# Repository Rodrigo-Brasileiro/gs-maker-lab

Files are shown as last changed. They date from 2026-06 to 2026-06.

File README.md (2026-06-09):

# TPGN Maker GS - Braco Robotico de Coleta de Amostras

Projeto desenvolvido para a Global Solution 2026 da FIAP, com foco em Industria Espacial, usando Arduino, servomotores e modelagem 3D parametrica em OpenSCAD.

O sistema simula um braco robotico de 2 graus de liberdade para operacoes de docking & retrieval, isto e, captura, manipulacao e recolhimento de amostras ou pequenos detritos em um cenario inspirado em microgravidade.

## Visao geral

O prototipo e composto por:

| Area | Descricao |
| --- | --- |
| Controle | Firmware Arduino com comandos via Monitor Serial |
| Atuadores | 2 micro servos SG90: articulacao do braco e garra |
| Sinalizacao | LED de status para indicar garra fechada |
| Simulacao | Circuito publico no Tinkercad |
| Modelagem | Pecas mecanicas parametrizadas em OpenSCAD |
| Impressao 3D | Arquivos STL exportados para braco, base, elo e dedos da garra |

## Objetivo

Criar um demonstrador funcional de um mecanismo robotico simples, capaz de:

- Subir e descer a articulacao principal do braco.
- Abrir e fechar uma garra mecanica acionada por servo.
- Sinalizar visualmente quando a amostra esta capturada.
- Representar, em escala didatica, uma aplicacao de coleta de amostras, manutencao orbital ou captura de detritos espaciais.

## Integrantes

| Nome | RM |
| --- | --- |
| Guilherme Rocha Bianchini | RM97974 |
| Nikolas Rodrigues Moura dos Santos | RM551566 |
| Pedro Henrique Pedrosa Tavares | RM97877 |
| Rodrigo Brasileiro | RM98952 |
| Thiago Jardim de Oliveira | RM551624 |

Grupo: `TPGN - TechPulse Global Network`

## Links da entrega

| Recurso | Link |
| --- | --- |
| Simulador do circuito no Tinkercad | [Abrir projeto](https://www.tinkercad.com/things/aPYhfb0wO8s/editel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) |

## Estrutura do repositorio

```text
TPGN_MAKER_GS/
|-- README.md
|-- src/
|   `-- braco_robotico.ino
`-- model/
    |-- braco_robotico.scad
    |-- garra.scad
    |-- braco_robotico.stl
    |-- arm_base.stl
    |-- arm_link.stl
    |-- garra.stl
    |-- garra_base.stl
    |-- driver_finger.stl
    `-- follower_finger.stl
```

## Hardware e componentes

| Componente | Funcao |
| --- | --- |
| Arduino Uno R3 | Controlador do circuito |
| 2x micro servo SG90 9g | Movimento do braco e abertura/fechamento da garra |
| LED | Indicador de garra fechada |
| Resistor 220 ohm | Limitacao de corrente do LED |
| Fonte externa 5 V  | Alimentacao recomendada para os servos |
| Protoboard e jumpers | Conexoes eletricas |

Importante: para montagem fisica, os servos devem ser alimentados por fonte externa de 5 V ou 6 V, mantendo GND comum com o Arduino. Evite alimentar os servos diretamente pelo pino 5V do Arduino.

## Pinagem

| Pino Arduino | Conexao |
| --- | --- |
| `D9` | Sinal do Servo 1 - articulacao do braco |
| `D10` | Sinal do Servo 2 - garra |
| `D7` | LED de status com resistor de 220 ohm |
| `GND` | Terra comum entre Arduino, fonte e servos |

## Firmware

O firmware esta em [`src/braco_robotico.ino`](src/braco_robotico.ino) e usa a biblioteca padrao `Servo.h`.

Configuracoes principais:

| Parametro | Valor |
| --- | --- |
| Baud rate | `9600` |
| Angulo inicial do braco | `90` graus |
| Limite minimo do braco | `10` graus |
| Limite maximo do braco | `170` graus |
| Passo por comando | `15` graus |
| Garra aberta | `120` graus |
| Garra fechada | `30` graus |
| Delay de movimento | `15 ms` por grau |

## Comandos do Monitor Serial

Abra o Monitor Serial em `9600 baud`, envie um caractere e pressione Enter.

| Comando | Acao | Servo |
| --- | --- | --- |
| `U` | Sobe a articulacao do braco | Servo 1 |
| `D` | Desce a articulacao do braco | Servo 1 |
| `O` | Abre a garra | Servo 2 |
| `C` | Fecha a garra | Servo 2 |
| `H` | Volta as garras a posição inicial | Servo 1 e 2 |

Comportamento do LED:

- LED aceso: garra fechada, representando amostra capturada.
- LED apagado: garra aberta.
- Comandos invalidos são informados no Monitor Serial.

## Modelos 3D

Os modelos foram criados em OpenSCAD de forma parametrica, permitindo ajustar dimensoes, folgas, encaixes e layout de exportacao.

| Arquivo | Descricao |
| --- | --- |
| `model/garra.scad` | Modelo parametrico da garra com engrenagens gemeas |
| `model/braco_robotico.scad` | Montagem completa do braco 2-DOF, importando a garra |
| `model/garra.stl` | STL da garra montada |
| `model/garra_base.stl` | STL da base da garra |
| `model/driver_finger.stl` | STL do dedo motor da garra |
| `model/follower_finger.stl` | STL do dedo seguidor da garra |
| `model/braco_robotico.stl` | STL da montagem do braco |
| `model/arm_base.stl` | STL da base do braco |
| `model/arm_link.stl` | STL do elo do braco |

### Garra

A garra usa um mecanismo de engrenagens gemeas. Um servo aciona o dedo motor, enquanto o dedo seguidor acompanha o movimento por engrenamento, fechando de forma simetrica. As pontas possuem geometria concava para envolver uma amostra esferica de referencia.

### Braço

O arquivo `braco_robotico.scad` reutiliza os modulos de `garra.scad` e adiciona:

- Base do braço.
- Suporte do ombro.
- Elo principal.
- Acoplamento da garra ao punho.
- Suporte opcional para LED.

## Como reproduzir

1. Abra o projeto do Tinkercad pelo link da entrega.
2. Verifique se o circuito usa GND comum entre Arduino e fonte dos servos.
3. Inicie a simulacao.
4. Abra o Monitor Serial em `9600 baud`.
5. Envie os comandos `U`, `D`, `O`, `C` e `H` para testar os movimentos.
6. Para uso fisico, abra `src/braco_robotico.ino` na Arduino IDE e envie o codigo para um Arduino Uno.
7. Para visualizar ou alterar as pecas, abra os arquivos `.scad` no OpenSCAD.
8. Para exportar novos STLs, renderize com `F6` e use `File > Export > Export as STL`.

## Tecnologias utilizadas

- Arduino Uno
- Arduino IDE
- Biblioteca `Servo.h`
- Tinkercad Circuits
- OpenSCAD
- Modelos STL para impressao 3D

## Relacao com ODS

O projeto se conecta ao ODS 9 - Industria, Inovacao e Infraestrutura, pois explora automacao, prototipagem, sistemas embarcados e modelagem mecanica aplicados a um problema inspirado na industria espacial.

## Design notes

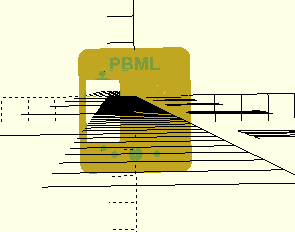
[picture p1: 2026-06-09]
imagens/suporte_vista_lateral.png

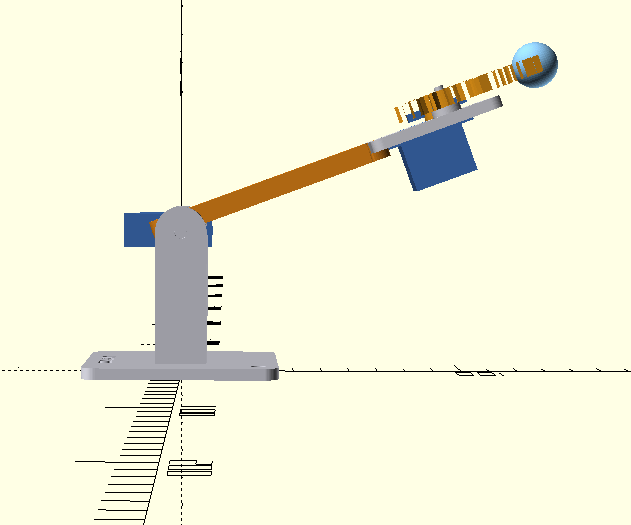
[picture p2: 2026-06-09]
imagens/vista_de_lado.png

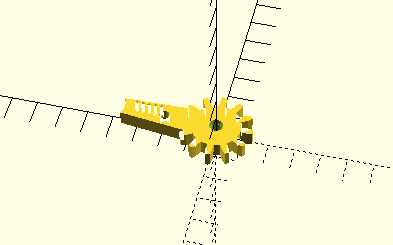
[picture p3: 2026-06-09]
imagens/garra_cilindrica.png

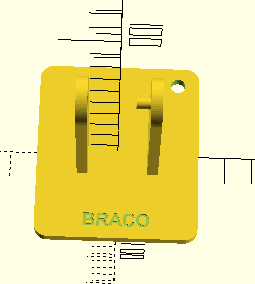
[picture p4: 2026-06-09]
imagens/suporte.png

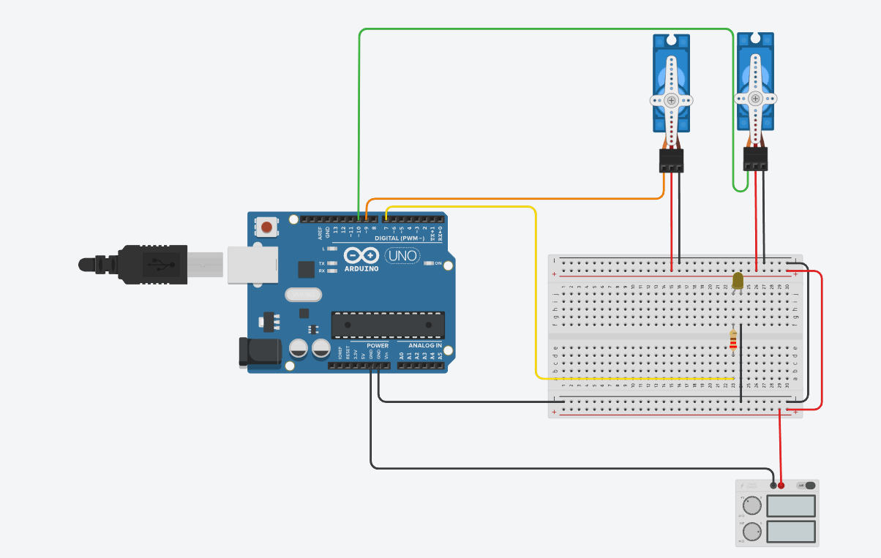
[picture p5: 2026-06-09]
imagens/circuito.png

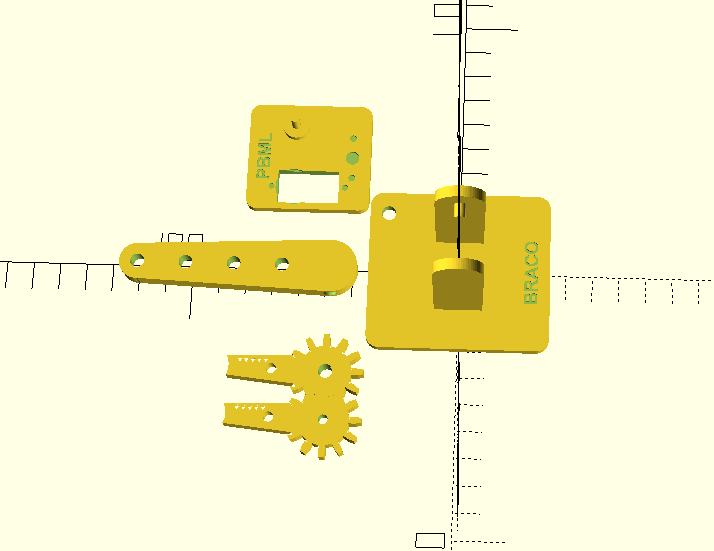
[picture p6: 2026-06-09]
imagens/componente_vista_superior.png

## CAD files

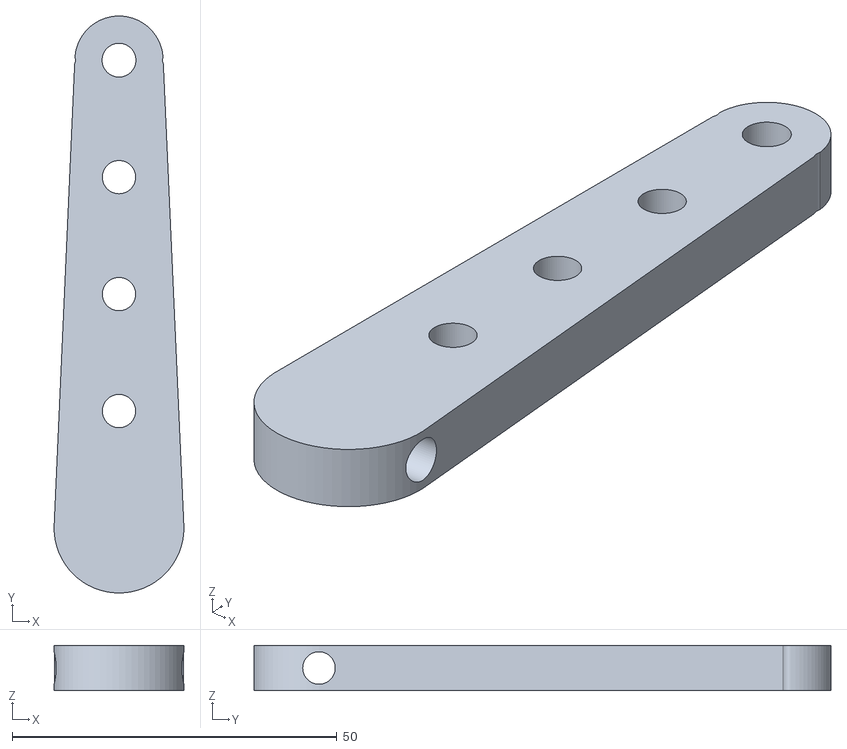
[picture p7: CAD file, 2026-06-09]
model/arm_link.stl
20.0 x 88.8 x 7.00

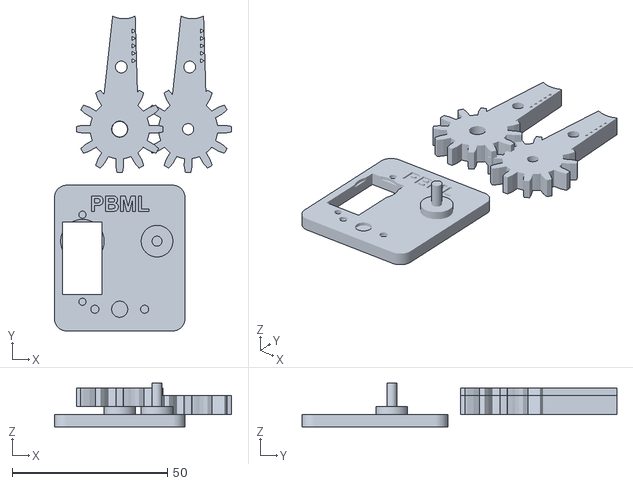
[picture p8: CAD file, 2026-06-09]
model/garra.stl
57.0 x 101.3 x 14.0

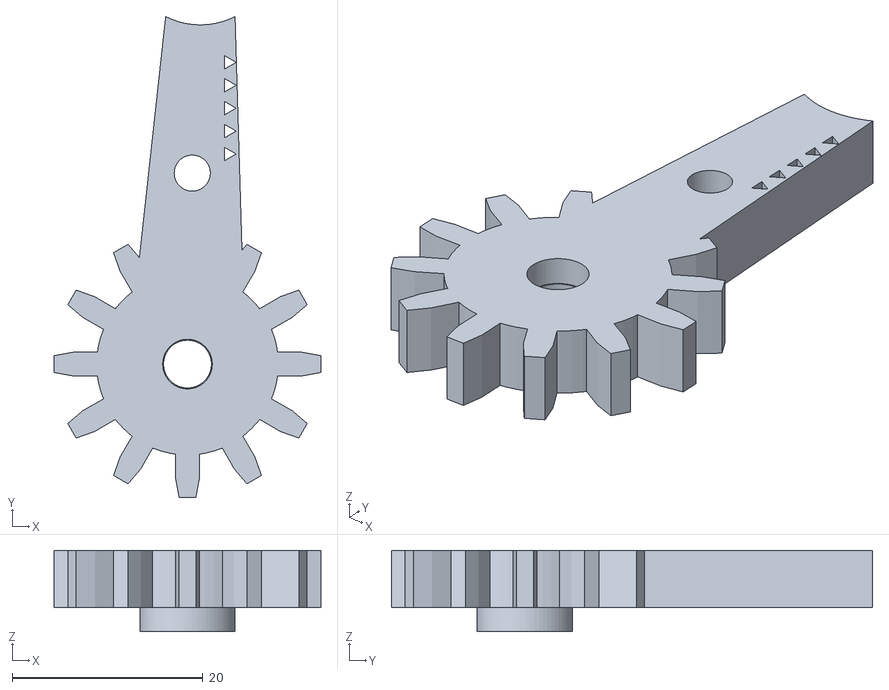
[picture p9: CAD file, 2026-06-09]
model/driver_finger.stl
27.9 x 50.4 x 8.50

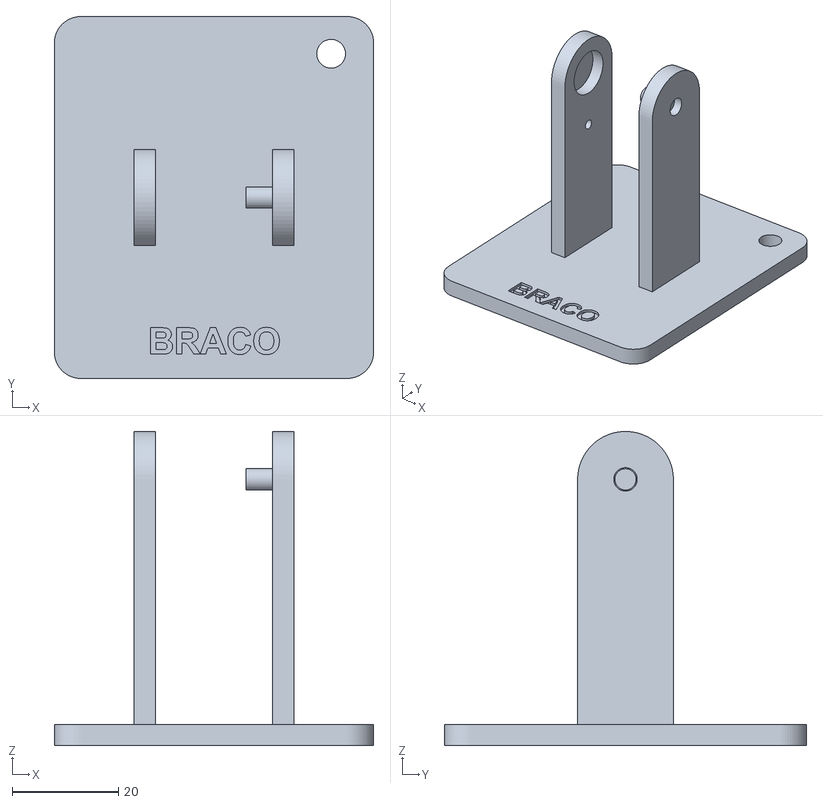
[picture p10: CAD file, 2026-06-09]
model/arm_base.stl
60.0 x 68.0 x 59.0

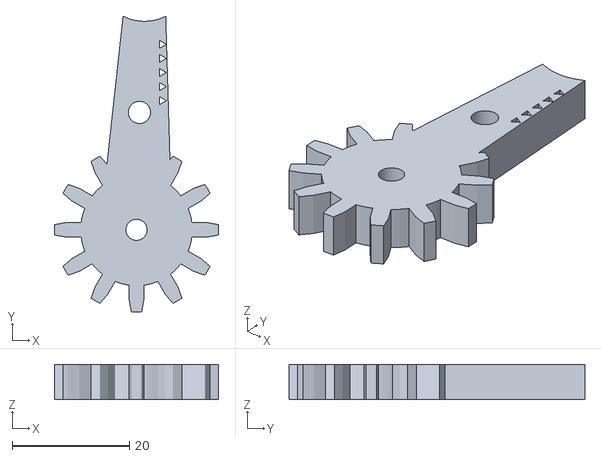
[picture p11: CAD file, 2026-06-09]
model/follower_finger.stl
27.9 x 50.4 x 6.00

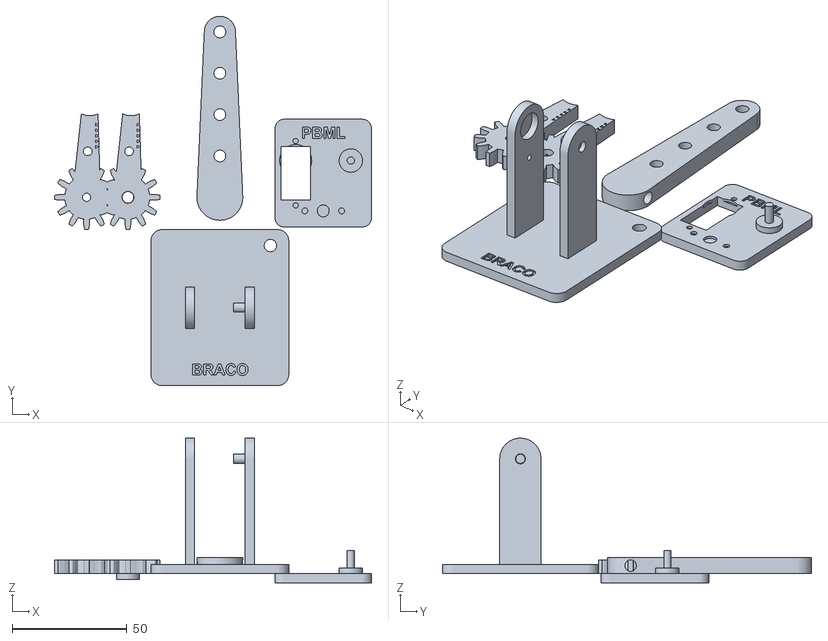
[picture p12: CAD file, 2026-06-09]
model/braco_robotico.stl
138.0 x 160.8 x 63.0

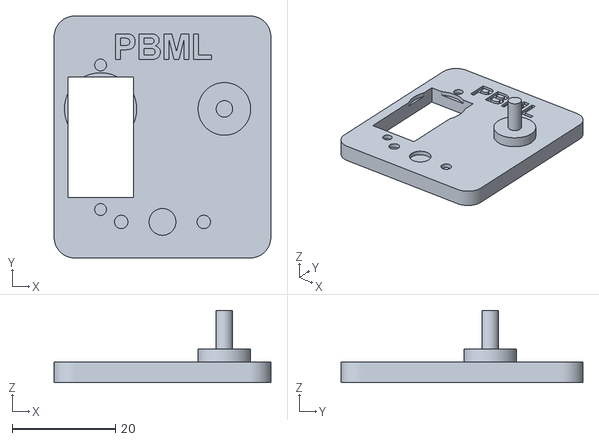
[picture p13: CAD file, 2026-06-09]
model/garra_base.stl
42.0 x 46.9 x 14.0

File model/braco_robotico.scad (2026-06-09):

// ============================================================================
//  Projeto : Braco Robotico de Coleta de Amostras (Docking & Retrieval)
//  Peca    : BRACO COMPLETO 2-DOF (ombro que sobe/desce + mao que abre/fecha)
//  Evento  : Global Solution 2026 - Industria Espacial
//  Curso   : FIAP - Engenharia de Software - 4o Ano (Presencial)
//  Materia : Project-Based Maker Lab (PBML)
//
//  Author  : RODRIGO BRASILEIRO - RM98952
//
//  Conceito: braco de 2 graus de liberdade fiel ao circuito de 2 servos.
//    - SERVO 1 (ombro): gira o elo p/ cima/baixo  -> comandos U / D (firmware)
//    - SERVO 2 (mao)  : abre/fecha a garra         -> comandos O / C (firmware)
//  A mao reaproveita o mecanismo de engrenagens gemeas validado em garra.scad.
//
//  Reuso modular: este arquivo IMPORTA garra.scad (modulos validados) sem
//  duplicar geometria. O include-guard impede a garra de renderizar sozinha.
//  Exportacao: render (F6) -> "Export as STL".
// ============================================================================

GARRA_AS_LIBRARY = true;          // suprime o render proprio do garra.scad
include <garra.scad>;             // reusa: base() da garra, dedos, sg90_ref, sample, rrect, P, params SG90

/* [ Selecao de peca p/ render/export ] */
show = "assembly";  // [assembly, arm_base, arm_link, garra_base, driver_finger, follower_finger, print_plate]

/* [ Qualidade ] */
$fn = 64;

// ---------------------------------------------------------------------------
//                                PARAMETROS DO BRACO
// ---------------------------------------------------------------------------

/* [ Ombro e elo ] */
arm_link_len    = 72.0;   // comprimento do elo (eixo do ombro -> punho)
shoulder_axis_h = 50.0;   // altura do eixo do ombro acima da mesa
shoulder_pose   = 20;     // angulo do elo no preview (0 = horizontal, + sobe)
link_w          = 16.0;   // largura do elo
link_th         = 7.0;    // espessura (altura impressa) do elo

/* [ Base e yoke (suporte do ombro) ] */
base_w_half     = 30.0;   // meia-largura da base
base_d_half     = 34.0;   // meia-profundidade da base
plate_th        = 4.0;    // espessura da placa da base
wall_t          = 4.0;    // espessura das paredes do yoke
yoke_gap        = 22.0;   // vao interno entre as paredes (precisa > link_w)
axis_cap_r      = 9.0;    // raio do topo arredondado das paredes (sobre o eixo)
idler_d         = 4.0;    // pino coaxial de apoio do elo (parede direita)

/* [ Acoplamento ao horn do servo 1 ] */
horn_bore_d     = shaft_d;   // furo do eixo no hub do elo (herdado da garra)
horn_screw_d    = 2.2;       // 2 furos p/ parafusar o elo no horn redondo

/* [ LED de status (opcional, na base) ] */
show_led_holder = true;
led_d           = 5.4;    // furo do LED de 5mm

// ---------------------------------------------------------------------------
//                          GRANDEZAS DERIVADAS
// ---------------------------------------------------------------------------
wall_x   = yoke_gap/2 + wall_t/2;        // centro X de cada parede do yoke
// deslocamento p/ encaixar a cauda da garra no punho do elo
hand_y   = arm_link_len - by0;           // by0 vem da garra (cauda traseira)

// ---------------------------------------------------------------------------
//                          BASE + YOKE (suporte do ombro)
// ---------------------------------------------------------------------------
module yoke_wall() {
    // parede no plano YZ (espessura wall_t em X), com topo arredondado no eixo
    union() {
        translate([-wall_t/2, -axis_cap_r, 0])
            cube([wall_t, axis_cap_r*2, shoulder_axis_h]);
        translate([0, 0, shoulder_axis_h])
            rotate([0, 90, 0]) cylinder(r = axis_cap_r, h = wall_t, center = true);
    }
}

module arm_base() {
    difference() {
        union() {
            // placa da base (topo em z = plate_th)
            rrect(-base_w_half, -base_d_half, base_w_half, base_d_half, plate_th, 5);
            // duas paredes do yoke
            for (s = [-1, 1]) translate([s * wall_x, 0, 0]) yoke_wall();
        }
        // furo do eixo do servo 1 na parede ESQUERDA (passagem do horn)
        translate([-wall_x - 1, 0, shoulder_axis_h])
            rotate([0, 90, 0]) cylinder(d = shaft_d + 6, h = wall_t + 2);
        // furos da flange do servo 1 (par vertical) - parede esquerda
        for (s = [-1, 1])
            translate([-wall_x - 1, 0, shoulder_axis_h + s * screw_span/2])
                rotate([0, 90, 0]) cylinder(d = screw_d, h = wall_t + 2);
        // furo do pino idler na parede DIREITA
        translate([wall_x - 1, 0, shoulder_axis_h])
            rotate([0, 90, 0]) cylinder(d = idler_d + 0.4, h = wall_t + 2);
        // furo do LED de status na frente da base
        if (show_led_holder)
            translate([base_w_half - 8, base_d_half - 7, -1])
                cylinder(d = led_d, h = plate_th + 2);
        // rebaixo/etiqueta
        translate([0, -base_d_half + 7, plate_th - 0.6])
            linear_extrude(1.2)
                text("BRACO", size = 5, halign = "center", valign = "center",
                     font = "Arial:style=Bold");
    }
    // pino idler solido apontando p/ dentro (-X) da parede direita
    translate([wall_x, 0, shoulder_axis_h])
        rotate([0, -90, 0]) cylinder(d = idler_d, h = wall_t + 3);
}

// ---------------------------------------------------------------------------
//                          ELO (braco) - gira sobre o eixo X do ombro
//  Frame local: hub em y=0; estende-se p/ +Y ate o punho (y = arm_link_len).
//  Espessura em Z (impresso deitado); furo do eixo passa em X pelo hub.
// ---------------------------------------------------------------------------
module arm_link() {
    difference() {
        union() {
            // viga afilada
            hull() {
                cylinder(d = link_w + 4, h = link_th);                 // hub do ombro
                translate([0, arm_link_len, 0]) cylinder(d = link_w*0.85, h = link_th);
            }
        }
        // furo do eixo do ombro (passa em X pelo hub)
        translate([-link_w, 0, link_th/2]) rotate([0, 90, 0])
            cylinder(d = horn_bore_d, h = 2*link_w);
        // 2 furos p/ parafusar o elo no horn (na face esquerda do hub)
        for (s = [-1, 1])
            translate([-link_w/2 - 0.5, 0, link_th/2 + s*6]) rotate([0, 90, 0])
                cylinder(d = horn_screw_d, h = link_w*0.6);
        // padrao de fixacao da GARRA no punho (furos em Z, casa com a base da garra)
        translate([0, arm_link_len, -1]) cylinder(d = arm_bore, h = link_th + 2);
        for (s = [-1, 1])
            translate([s * arm_pattern/2, arm_link_len, -1])
                cylinder(d = arm_screw_d, h = link_th + 2);
        // aligeiramento
        for (i = [1 : 3])
            translate([0, arm_link_len * i/4, -1]) cylinder(d = link_w*0.32, h = link_th + 2);
    }
}

// ---------------------------------------------------------------------------
//                          MAO (garra) - wrapper de reuso
// ---------------------------------------------------------------------------
module gripper_hand() {
    // a montagem da garra (base + servo 2 + dedos + amostra) ja validada
    assembly();
}

// ---------------------------------------------------------------------------
//                          MONTAGEM COMPLETA (preview)
// ---------------------------------------------------------------------------
module arm_assembly() {
    color([0.82, 0.82, 0.86]) arm_base();

    // servo 1 (ombro) na parede esquerda, eixo horizontal (+X)
    translate([-wall_x, 0, shoulder_axis_h]) rotate([0, 90, 0]) sg90_ref();

    // elo + mao giram juntos sobre o eixo do ombro
    translate([0, 0, shoulder_axis_h]) rotate([shoulder_pose, 0, 0]) {
        color([0.93, 0.55, 0.10]) arm_link();
        // garra encaixada no punho (cauda no punho, dedos seguem +Y), sobre o elo
        translate([0, hand_y, link_th]) gripper_hand();
    }
}

// ---------------------------------------------------------------------------
//                          LAYOUT DE IMPRESSAO
// ---------------------------------------------------------------------------
module arm_print_plate() {
    arm_base();
    translate([0, base_d_half + 14, 0]) arm_link();
    translate([-40, base_d_half + 14, 0]) driver_finger();
    translate([-58, base_d_half + 14, 0]) follower_finger();
    translate([45, base_d_half + 30, 0]) base();     // base da garra
}
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

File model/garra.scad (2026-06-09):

// ============================================================================
//  Projeto : Braco Robotico de Coleta de Amostras (Docking & Retrieval)
//  Peca    : GARRA (Grip) - mecanismo de engrenagens gemeas acionado por 1 servo
//  Evento  : Global Solution 2026 - Industria Espacial
//  Curso   : FIAP - Engenharia de Software - 4o Ano (Presencial)
//  Materia : Project-Based Maker Lab (PBML)
//
//  Author  : RODRIGO BRASILEIRO - RM98952
//
//  Conceito: garra de captura de amostras/detritos em microgravidade. Um unico
//  servo SG90 (9g) aciona o "dedo motor"; um segundo dedo (seguidor) engrena no
//  primeiro e fecha de forma simetrica. As pontas tem um bercco concavo que
//  abraca uma amostra esferica (ex.: regolito / detrito orbital). Compativel com
//  o firmware: comando O abre a garra (GRIP_OPEN) e C fecha (GRIP_CLOSE).
//
//  TUDO E PARAMETRICO: altere a secao "PARAMETROS" para reescalar a peca.
//  Exportacao: render (F6) e depois "Export as STL" -> garra.stl
// ============================================================================

/* [ Selecao de peca p/ render/export ] */
// "assembly" para ver montado; demais para exportar/imprimir cada peca.
part = "assembly";  // [assembly, base, driver_finger, follower_finger, sample, print_plate]

/* [ Qualidade ] */
$fn = 64;

// ---------------------------------------------------------------------------
//                                PARAMETROS
// ---------------------------------------------------------------------------

/* [ Servo SG90 (9g) - encaixe ] */
servo_l       = 22.8;   // comprimento do corpo
servo_w       = 12.2;   // largura do corpo
servo_h       = 22.5;   // altura do corpo
servo_clear   = 0.5;    // folga de encaixe (impressao)
shaft_offset  = 5.9;    // eixo a partir de uma extremidade do corpo
shaft_d       = 5.0;    // diametro do eixo estriado (acopla ao horn)
flange_l      = 32.2;   // comprimento total com as abas de fixacao
flange_t      = 2.6;    // espessura da aba
flange_drop   = 2.5;    // distancia do topo do corpo ate a aba
screw_span    = 28.0;   // distancia entre os furos das abas
screw_d       = 2.3;    // furo das abas (parafuso M2)
horn_screw_d  = 2.2;    // parafuso central do horn

/* [ Engrenagens dos dedos ] */
gear_teeth    = 12;     // numero de dentes
gear_mod      = 2.0;    // modulo da engrenagem
gear_th       = 6.0;    // espessura (altura) da engrenagem/dedo
pivot_d       = 3.2;    // pino do dedo seguidor

/* [ Dedos / garra ] */
finger_len    = 40.0;   // comprimento do dedo (do eixo ate a ponta)
finger_w      = 9.0;    // largura do dedo
grip_n        = 5;      // n. de serrilhas de aderencia
tip_reach     = 0.85;   // fracao do comprimento usada p/ as pontas se encontrarem
open_angle    = 12;     // abertura no preview (graus a partir da garra FECHADA)
sample_d      = 16.0;   // diametro da amostra esferica (referencia)

/* [ Base / suporte ] */
base_th       = 4.0;    // espessura da base
standoff      = 2.5;    // folga vertical entre base e engrenagens
base_margin   = 9.0;    // margem ao redor dos eixos

/* [ Interface com o braco (link/articulacao) ] */
arm_bore      = 5.2;    // furo central de acoplamento ao braco
arm_screw_d   = 2.6;    // furos do padrao de fixacao
arm_pattern   = 16.0;   // distancia entre furos de fixacao no braco

/* [ Etiqueta ] */
show_label    = true;
label_txt     = "PBML";

// ---------------------------------------------------------------------------
//                          GRANDEZAS DERIVADAS
// ---------------------------------------------------------------------------
pitch_r  = gear_mod * gear_teeth / 2;     // raio primitivo
out_r    = pitch_r + gear_mod;            // raio externo
root_r   = pitch_r - 1.25 * gear_mod;     // raio de base
center_d = gear_mod * gear_teeth;         // distancia entre eixos (engr. iguais)

sx = -center_d / 2;   // eixo do dedo MOTOR (alinhado ao eixo do servo)
fx =  center_d / 2;   // eixo do dedo SEGUIDOR (pino)
body_cy = shaft_offset - servo_l / 2;     // centro Y do corpo do servo (eixo em y=0)

// inclinacao interna p/ as pontas se encontrarem no centro (garra fechada)
A_close = atan2(center_d / 2, finger_len * tip_reach);

// limites da base
bx0 = sx - base_margin;
bx1 = fx + base_margin;
by0 = body_cy - servo_l/2 - 12;           // cauda traseira p/ fixacao no braco
by1 = out_r + 4;                          // frente (lado dos dedos)

// ---------------------------------------------------------------------------
//                          UTILITARIOS DE GEOMETRIA
// ---------------------------------------------------------------------------
function P(r, a) = [ r * cos(a), r * sin(a) ];

// Retangulo de cantos arredondados (canto inferior-esq em x0,y0)
module rrect(x0, y0, x1, y1, h, r) {
    hull() {
        translate([x0 + r, y0 + r, 0]) cylinder(r = r, h = h);
        translate([x1 - r, y0 + r, 0]) cylinder(r = r, h = h);
        translate([x1 - r, y1 - r, 0]) cylinder(r = r, h = h);
        translate([x0 + r, y1 - r, 0]) cylinder(r = r, h = h);
    }
}

// Perfil 2D de engrenagem (dentes trapezoidais que engrenam)
module gear_2d(teeth, m) {
    rp = m * teeth / 2;
    ro = rp + m;
    rr = rp - 1.25 * m;
    a  = 360 / teeth;
    union() {
        circle(r = rr + 0.02);
        for (i = [0 : teeth - 1])
            rotate(i * a)
                polygon([
                    P(rr, -a * 0.25), P(rp, -a * 0.20), P(ro, -a * 0.12),
                    P(ro,  a * 0.12), P(rp,  a * 0.20), P(rr,  a * 0.25)
                ]);
    }
}

// ---------------------------------------------------------------------------
//                          PERFIL DO DEDO (2D)
//  Aponta para +Y; lado interno (que segura a amostra) = +X.
// ---------------------------------------------------------------------------
module finger_2d() {
    difference() {
        union() {
            gear_2d(gear_teeth, gear_mod);             // engrenagem do dedo
            // braco do dedo
            hull() {
                translate([0, 2])               circle(d = finger_w + 3);
                translate([1.5, finger_len])    circle(d = finger_w * 0.75);
            }
            // gancho/ponta curvando para dentro (+X)
            hull() {
                translate([1.5, finger_len])                          circle(d = finger_w * 0.75);
                translate([finger_w * 0.7, finger_len + finger_w*0.15]) circle(d = finger_w * 0.5);
            }
        }
        // bercco concavo da amostra na PONTA (abre para frente, +Y).
        // os dois dedos juntos formam o bercco que abraca a esfera.
        translate([finger_w * 0.15, finger_len + sample_d * 0.22]) circle(r = sample_d / 2);
        // serrilhas de aderencia na face interna proxima da ponta
        for (i = [0 : grip_n - 1])
            translate([finger_w / 2 - 0.2, finger_len * 0.55 + i * (finger_len * 0.06)])
                circle(r = 0.8, $fn = 3);
        // furo de aligeiramento no corpo do braco
        translate([0.5, finger_len * 0.5]) circle(d = finger_w * 0.42);
    }
}

// ---------------------------------------------------------------------------
//                          DEDOS (3D)
// ---------------------------------------------------------------------------
// Dedo MOTOR: acopla ao eixo/horn do servo (cubo central removido = encaixe).
module driver_finger() {
    difference() {
        union() {
            linear_extrude(gear_th) finger_2d();
            // cubo de reforco do acoplamento sob a engrenagem
            translate([0, 0, -standoff]) cylinder(d = shaft_d + 5, h = standoff + 0.1);
        }
        // furo passante do eixo estriado
        translate([0, 0, -standoff - 1]) cylinder(d = shaft_d, h = gear_th + standoff + 2);
        // rebaixo p/ parafuso central do horn
        translate([0, 0, gear_th - 2.4]) cylinder(d = horn_screw_d + 3, h = 3);
    }
}

// Dedo SEGUIDOR: gira livre sobre o pino da base.
module follower_finger() {
    difference() {
        linear_extrude(gear_th) finger_2d();
        translate([0, 0, -1]) cylinder(d = pivot_d + 0.4, h = gear_th + 2);  // mancal
    }
}

// ---------------------------------------------------------------------------
//                          AMOSTRA (referencia)
// ---------------------------------------------------------------------------
module sample() {
    sphere(d = sample_d);
}
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

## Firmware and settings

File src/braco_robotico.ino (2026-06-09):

//
// Comandos para o monitor Serial 
// U -> Up : sobe a articulacao do braco
// D -> Down : desce a articulacao do braco
// O -> Open : abre a garra
// C -> Close : fecha a garra (captura a amostra)
// H -> Home : retorna a posicao neutra

#include <Servo.h>
// Mapeamento dos pinos
const uint8_t PIN_SERVO_ARM = 9; // Articulacao (Up / Down)
const uint8_t PIN_SERVO_GRIP = 10; // Garra (Open / Close)
const uint8_t PIN_LED_STATUS = 7; // LED de status

const int ARM_MIN = 10; // angulo minimo da articulacao
const int ARM_MAX = 170; // angulo maximo da articulacao
const int ARM_STEP = 15; // incremento de angulo por comando U/D
const int ARM_HOME = 90; // posicao neutra da articulacao
const int GRIP_OPEN = 120; // angulo da garra aberta
const int GRIP_CLOSE = 30; // angulo da garra fechada 
const int MOVE_DELAY = 15; // ms entre cada grau

Servo servoArm;
Servo servoGrip;
int armAngle = ARM_HOME; // posicao atual da articulacao
int gripAngle = GRIP_OPEN; // posicao atual da garra
// 
// Move um servo suavemente o angulo, grau a grau.
//
void moveSmooth(Servo &s, int from, int to) {
 if (to >= from) {
 for (int a = from; a <= to; a++) { s.write(a); delay(MOVE_DELAY); }
 } else {
 for (int a = from; a >= to; a--) { s.write(a); delay(MOVE_DELAY); }
 }
}
// Pisca o LED de status
void blinkStatus(int times) {
 for (int i = 0; i < times; i++) {
 digitalWrite(PIN_LED_STATUS, HIGH); delay(120);
 digitalWrite(PIN_LED_STATUS, LOW); delay(120);
 }
}
// LED aceso = garra fechada; apagado = garra aberta.
void updateStatusLed() {
 digitalWrite(PIN_LED_STATUS, (gripAngle == GRIP_CLOSE) ? HIGH : LOW);
}
void printHelp() {
 Serial.println(F("BRACO ROBOTICO - COMANDOS"));
 Serial.println(F(" U -> Sobe articulacao (Up)"));
 Serial.println(F(" D -> Desce articulacao (Down)"));
 Serial.println(F(" O -> Abre garra (Open)"));
 Serial.println(F(" C -> Fecha garra (Close)"));
 Serial.println(F(" H -> Home (posicao neutra)"));
}
void printState() {
 Serial.print(F("[STATUS] Articulacao: "));
 Serial.print(armAngle);
 Serial.print(F(" deg | Garra: "));
 Serial.print((gripAngle == GRIP_OPEN) ? F("ABERTA") : F("FECHADA"));
 Serial.print(F(" ("));
 Serial.print(gripAngle);
 Serial.println(F(" deg)"));
}
void setup() {
 Serial.begin(9600);
 pinMode(PIN_LED_STATUS, OUTPUT);
 digitalWrite(PIN_LED_STATUS, LOW);
 servoArm.attach(PIN_SERVO_ARM);
 servoGrip.attach(PIN_SERVO_GRIP);
 // Posiciona o braco na posicao inicial.
 servoArm.write(armAngle);
 servoGrip.write(gripAngle);
 blinkStatus(2); // sinaliza inicializacao bem-sucedida
 Serial.println(F("Braco robotico inicializado. Sistema pronto."));
 printHelp();
 printState();
}
void loop() {
 if (!Serial.available()) return;
 char cmd = Serial.read();
 // Ignora caracteres de controle (Enter / espaco).
 if (cmd == '\n' || cmd == '\r' || cmd == ' ') return;
 cmd = toupper(cmd);
 digitalWrite(PIN_LED_STATUS, HIGH); // LED aceso = executando comando
 switch (cmd) {
 case 'U': { // Up - sobe articulacao
 int target = min(armAngle + ARM_STEP, ARM_MAX);
 moveSmooth(servoArm, armAngle, target);
 armAngle = target;
 Serial.println(F("UP: articulacao subindo"));
 break;
 }
 case 'D': { // Down - desce articulacao
 int target = max(armAngle - ARM_STEP, ARM_MIN);
 moveSmooth(servoArm, armAngle, target);
 armAngle = target;
 Serial.println(F("DOWN: articulacao descendo"));
 break;
 }
 case 'O': { // Open - abre a garra
 moveSmooth(servoGrip, gripAngle, GRIP_OPEN);
 gripAngle = GRIP_OPEN;
 Serial.println(F("OPEN: garra aberta"));
 break;
 }
 case 'C': { // Close - fecha a garra
 moveSmooth(servoGrip, gripAngle, GRIP_CLOSE);
 gripAngle = GRIP_CLOSE;
 Serial.println(F("CLOSE: amostra capturada"));
 break;
 }
 case 'H': { // Home - posicao neutra
 moveSmooth(servoArm, armAngle, ARM_HOME);
 armAngle = ARM_HOME;
 moveSmooth(servoGrip, gripAngle, GRIP_OPEN);
 gripAngle = GRIP_OPEN;
 Serial.println(F(">> HOME: posicao neutra"));
 break;
 }
 }
 updateStatusLed(); // LED reflete o estado final da garra
 printState();
}

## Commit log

2026-06-09 Adds all repository
    [arm_base.stl, arm_link.stl, braco_robotico.scad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]
2026-06-09 improves read.me file
    Updated README to provide detailed project information including objectives, components, and instructions for the TPGN Maker GS robotic arm.
2026-06-09 Fix spelling and update servo power supply details
    Corrected spelling of 'são' in the README and updated power supply information for servos.
2026-06-09 Update README with LED behavior details
    Added LED behavior description to README.
